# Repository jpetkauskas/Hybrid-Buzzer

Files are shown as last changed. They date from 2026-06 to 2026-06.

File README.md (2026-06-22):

# Hybrid Quiz Bowl Buzzers
***[Try a demo of the Reader Console here!](https://jpetkauskas.github.io/Hybrid-Buzzer/)***

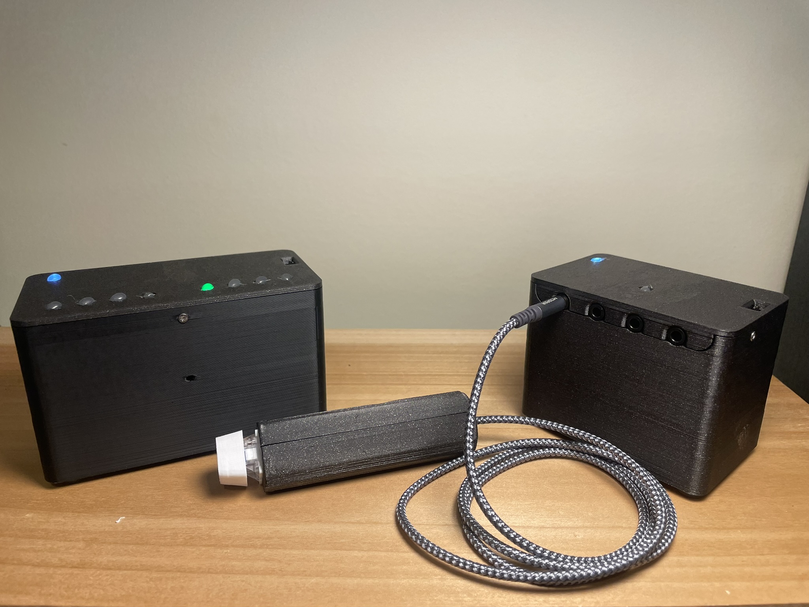
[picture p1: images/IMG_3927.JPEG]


This project uses three ESP32 based boards communicating via a unidirectional ESP-NOW link for robust, low latency Quizbowl lockout arbitration. A custom autopairing algorithm eliminates hardcoded MAC addresses and improves usability. The receiver also runs a novel SoftAP web server which hosts a scoring terminal for the reader, digitizing and simplifying tedious quizbowl scoring and adding analysis capability. Synchronized buzzer timing system  coordinates transmitter nodes based on receiver time, arbitrating winner based on incoming timestamps so that near-simultaneous buzzes aren't dropped, reaching 50/50 performance on true-simultaneous buzzes, 95/5 on 25uS deltas, and 100/0 correct arbitration for deltas >=50 uS (0.5 ms).

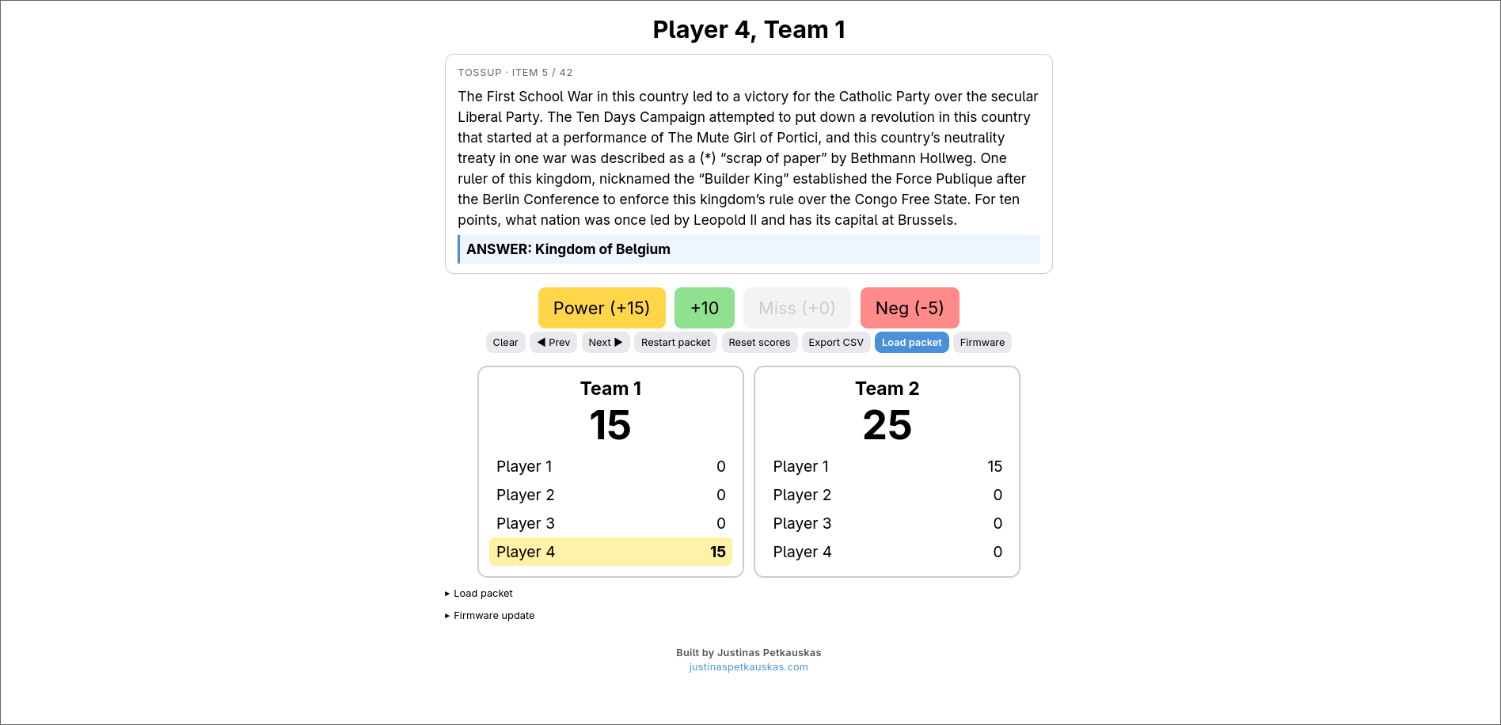
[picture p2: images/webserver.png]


I built these buzzers to replace my high school teams' aging wired set. The hybrid approach—wireless team stations with wired individual clickers—is more convenient than fully wired systems and scales more efficiently than fully wireless approaches. 

[See my writeup for more details.](https://justinaspetkauskas.com/writeups/hybrid-buzzers)

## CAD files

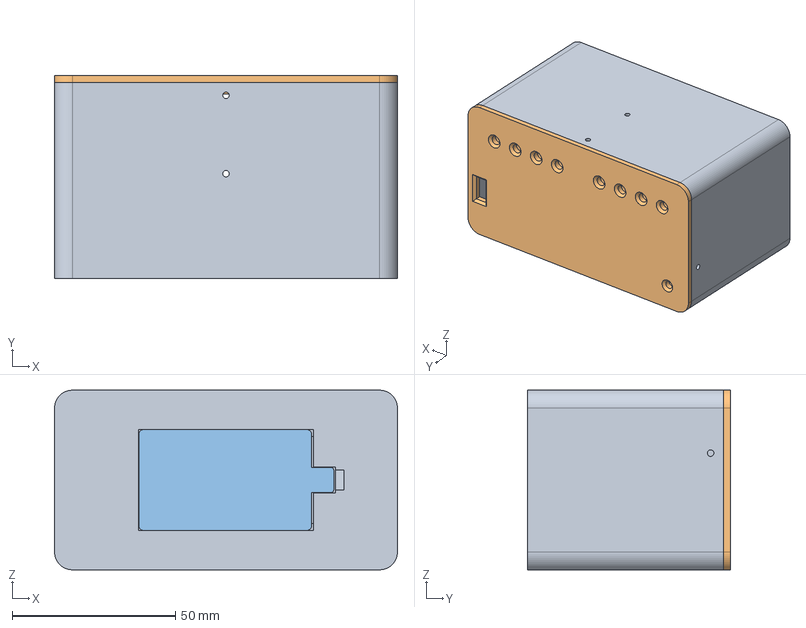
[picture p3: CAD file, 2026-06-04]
CAD/Receiver/receiver_assembly.stp
105.0 x 62.0 x 55.0 mm
receiver_enclosure
receiver_top_plate
receiver_battery_door

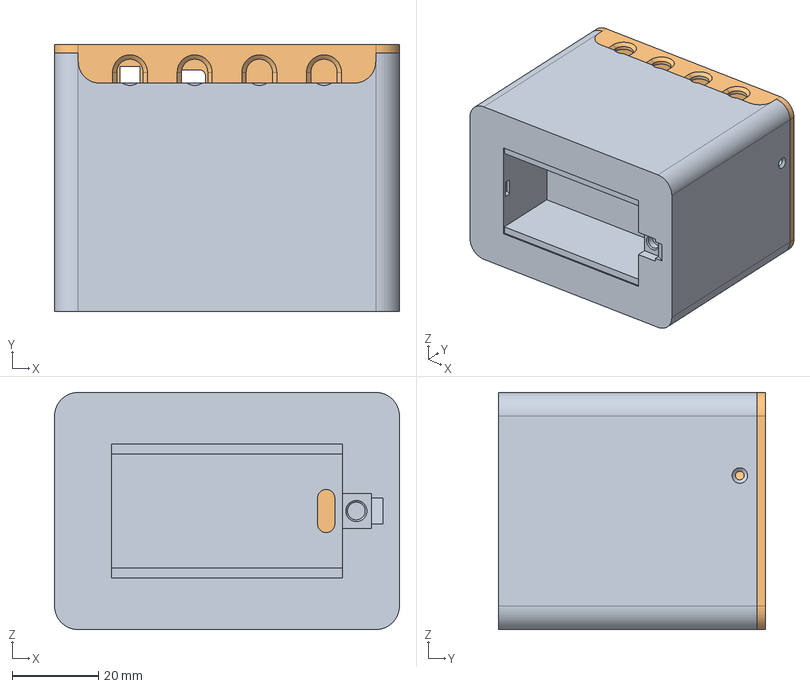
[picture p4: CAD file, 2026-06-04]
CAD/Transmitter/transmitter_assembly.stp
80.0 x 62.0 x 55.0 mm
transmitter_enclosure
transmitter_top_cover

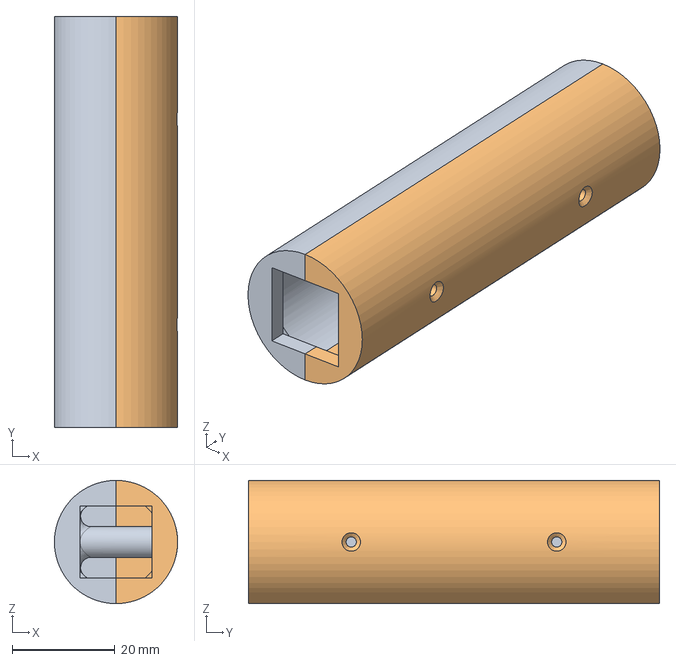
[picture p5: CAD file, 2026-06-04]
CAD/Clicker/Clicker.stp
24.0 x 80.0 x 24.0 mm
clicker_b
clicker_a

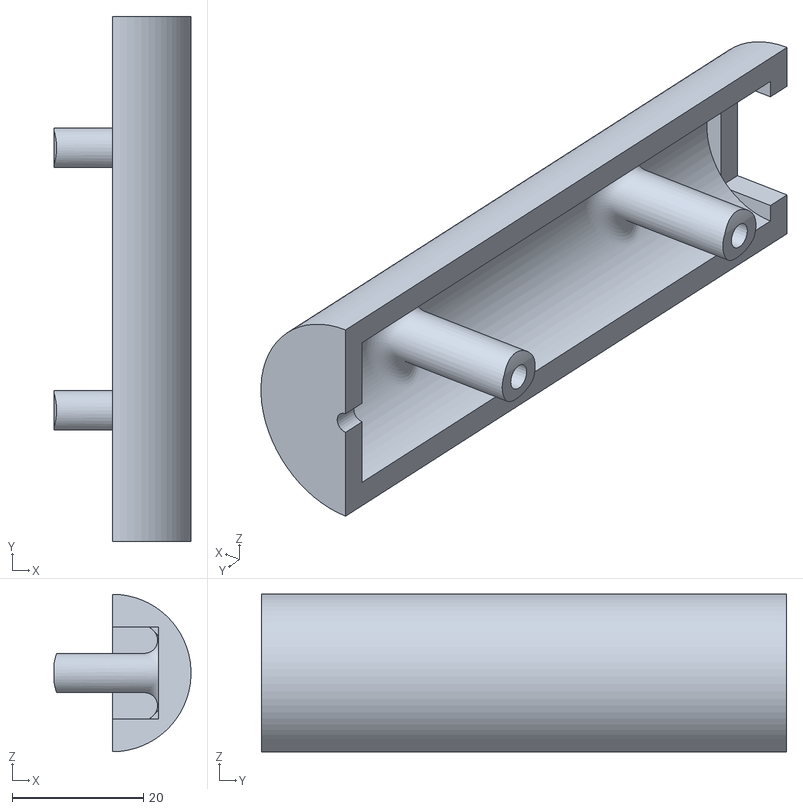
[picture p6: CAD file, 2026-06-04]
CAD/Clicker/Meshes/clicker_b.stl
20.9 x 80.0 x 24.0

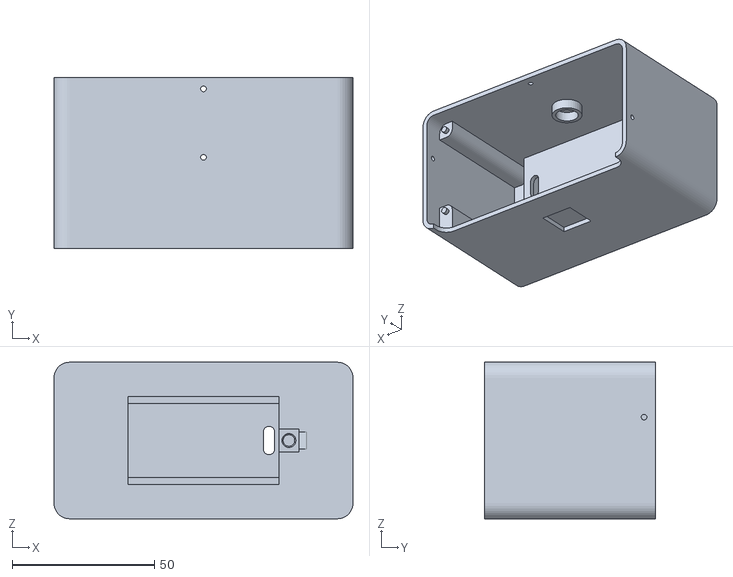
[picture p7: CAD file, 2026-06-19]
CAD/Receiver/Meshes/receiver_enclosure.stl
105.0 x 60.0 x 55.0

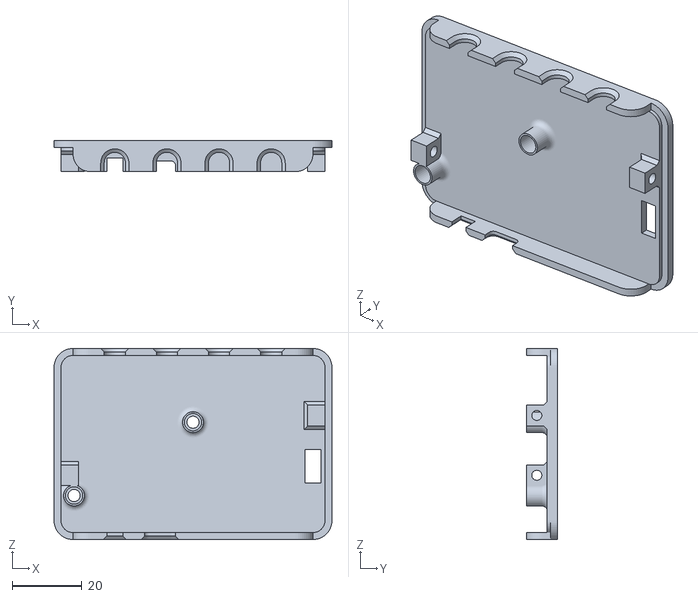
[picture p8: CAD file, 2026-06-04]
CAD/Transmitter/Meshes/transmitter_top_cover.stl
80.0 x 9.00 x 55.0

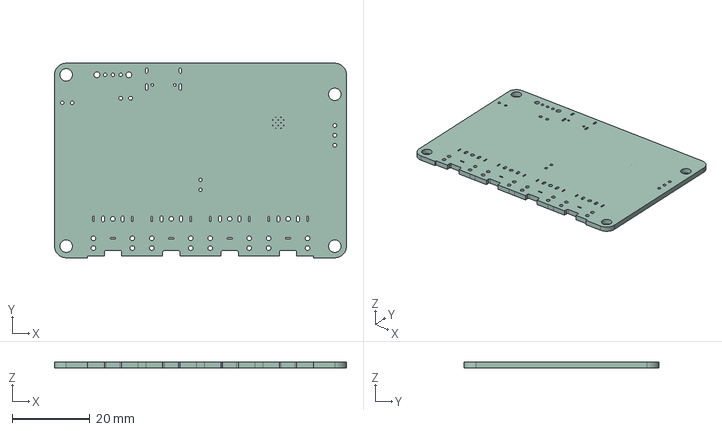
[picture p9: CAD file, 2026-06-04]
EDA/Transmitter/transmitter.step
75.0 x 50.0 x 1.51 mm

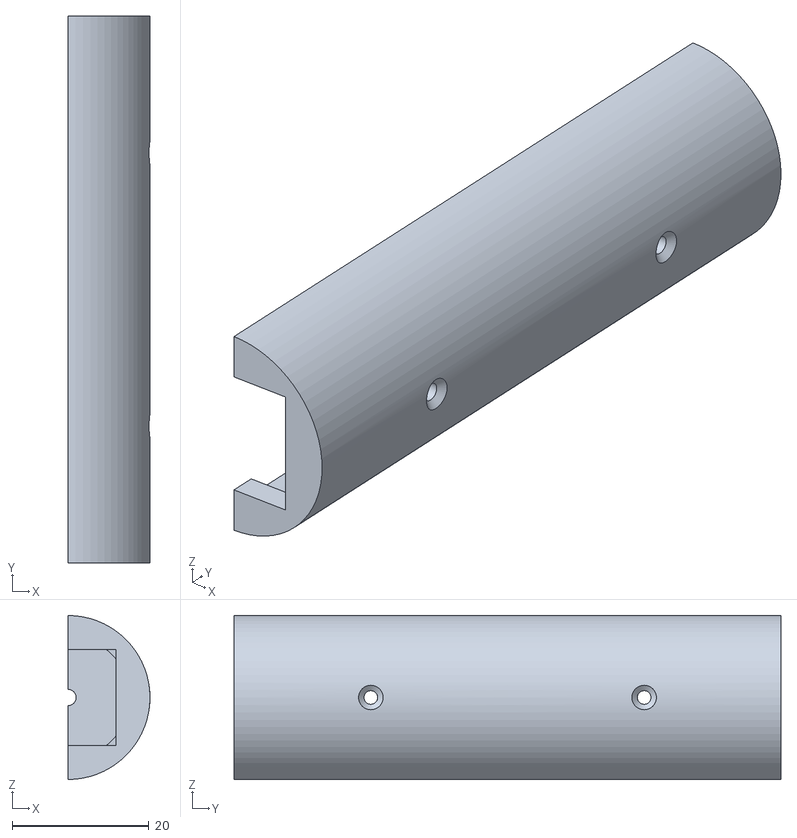
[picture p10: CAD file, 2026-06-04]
CAD/Clicker/Meshes/clicker_a.stl
12.0 x 80.0 x 24.0

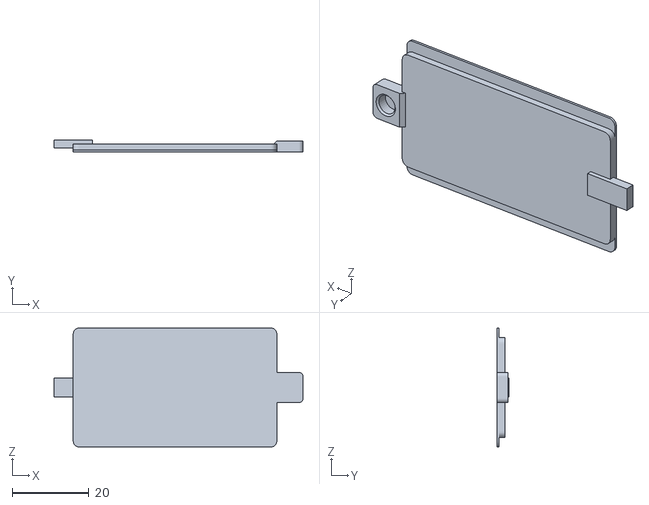
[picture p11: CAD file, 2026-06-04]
CAD/Receiver/Meshes/receiver_battery_door.stl
64.7 x 3.00 x 30.9

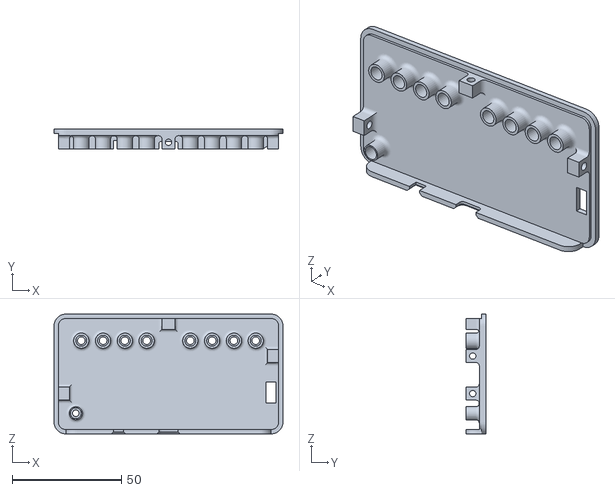
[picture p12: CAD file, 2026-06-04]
CAD/Receiver/Meshes/receiver_top_plate.stl
105.0 x 9.00 x 55.0

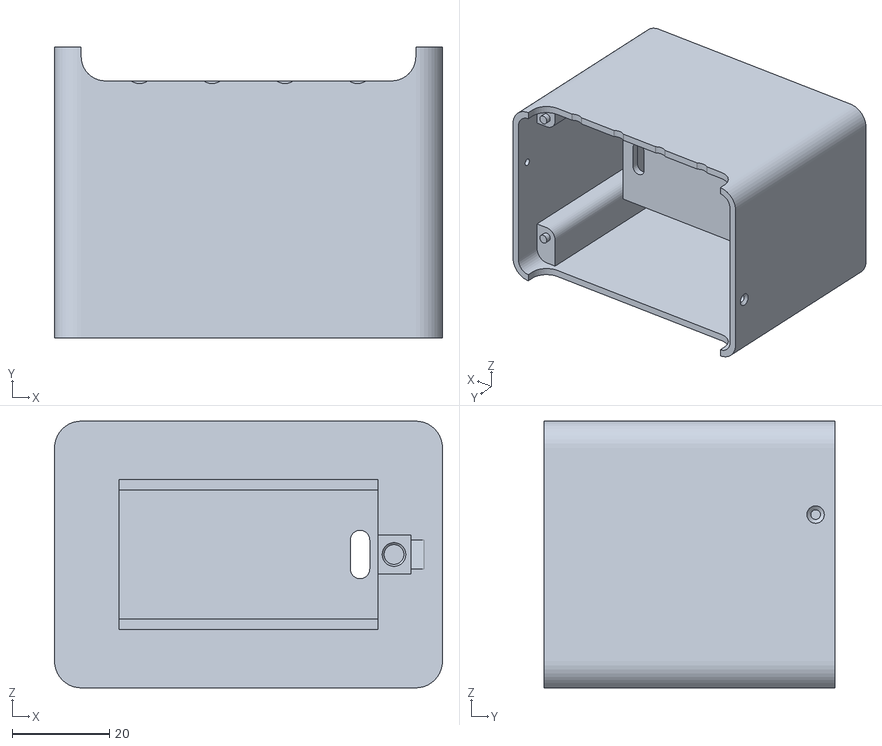
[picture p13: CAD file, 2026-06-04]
CAD/Transmitter/Meshes/transmitter_enclosure.stl
80.0 x 60.0 x 55.0

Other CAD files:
CAD/Clicker/Clicker.f3z
CAD/Receiver/receiver_assembly.f3z
CAD/Transmitter/transmitter_assembly.f3z

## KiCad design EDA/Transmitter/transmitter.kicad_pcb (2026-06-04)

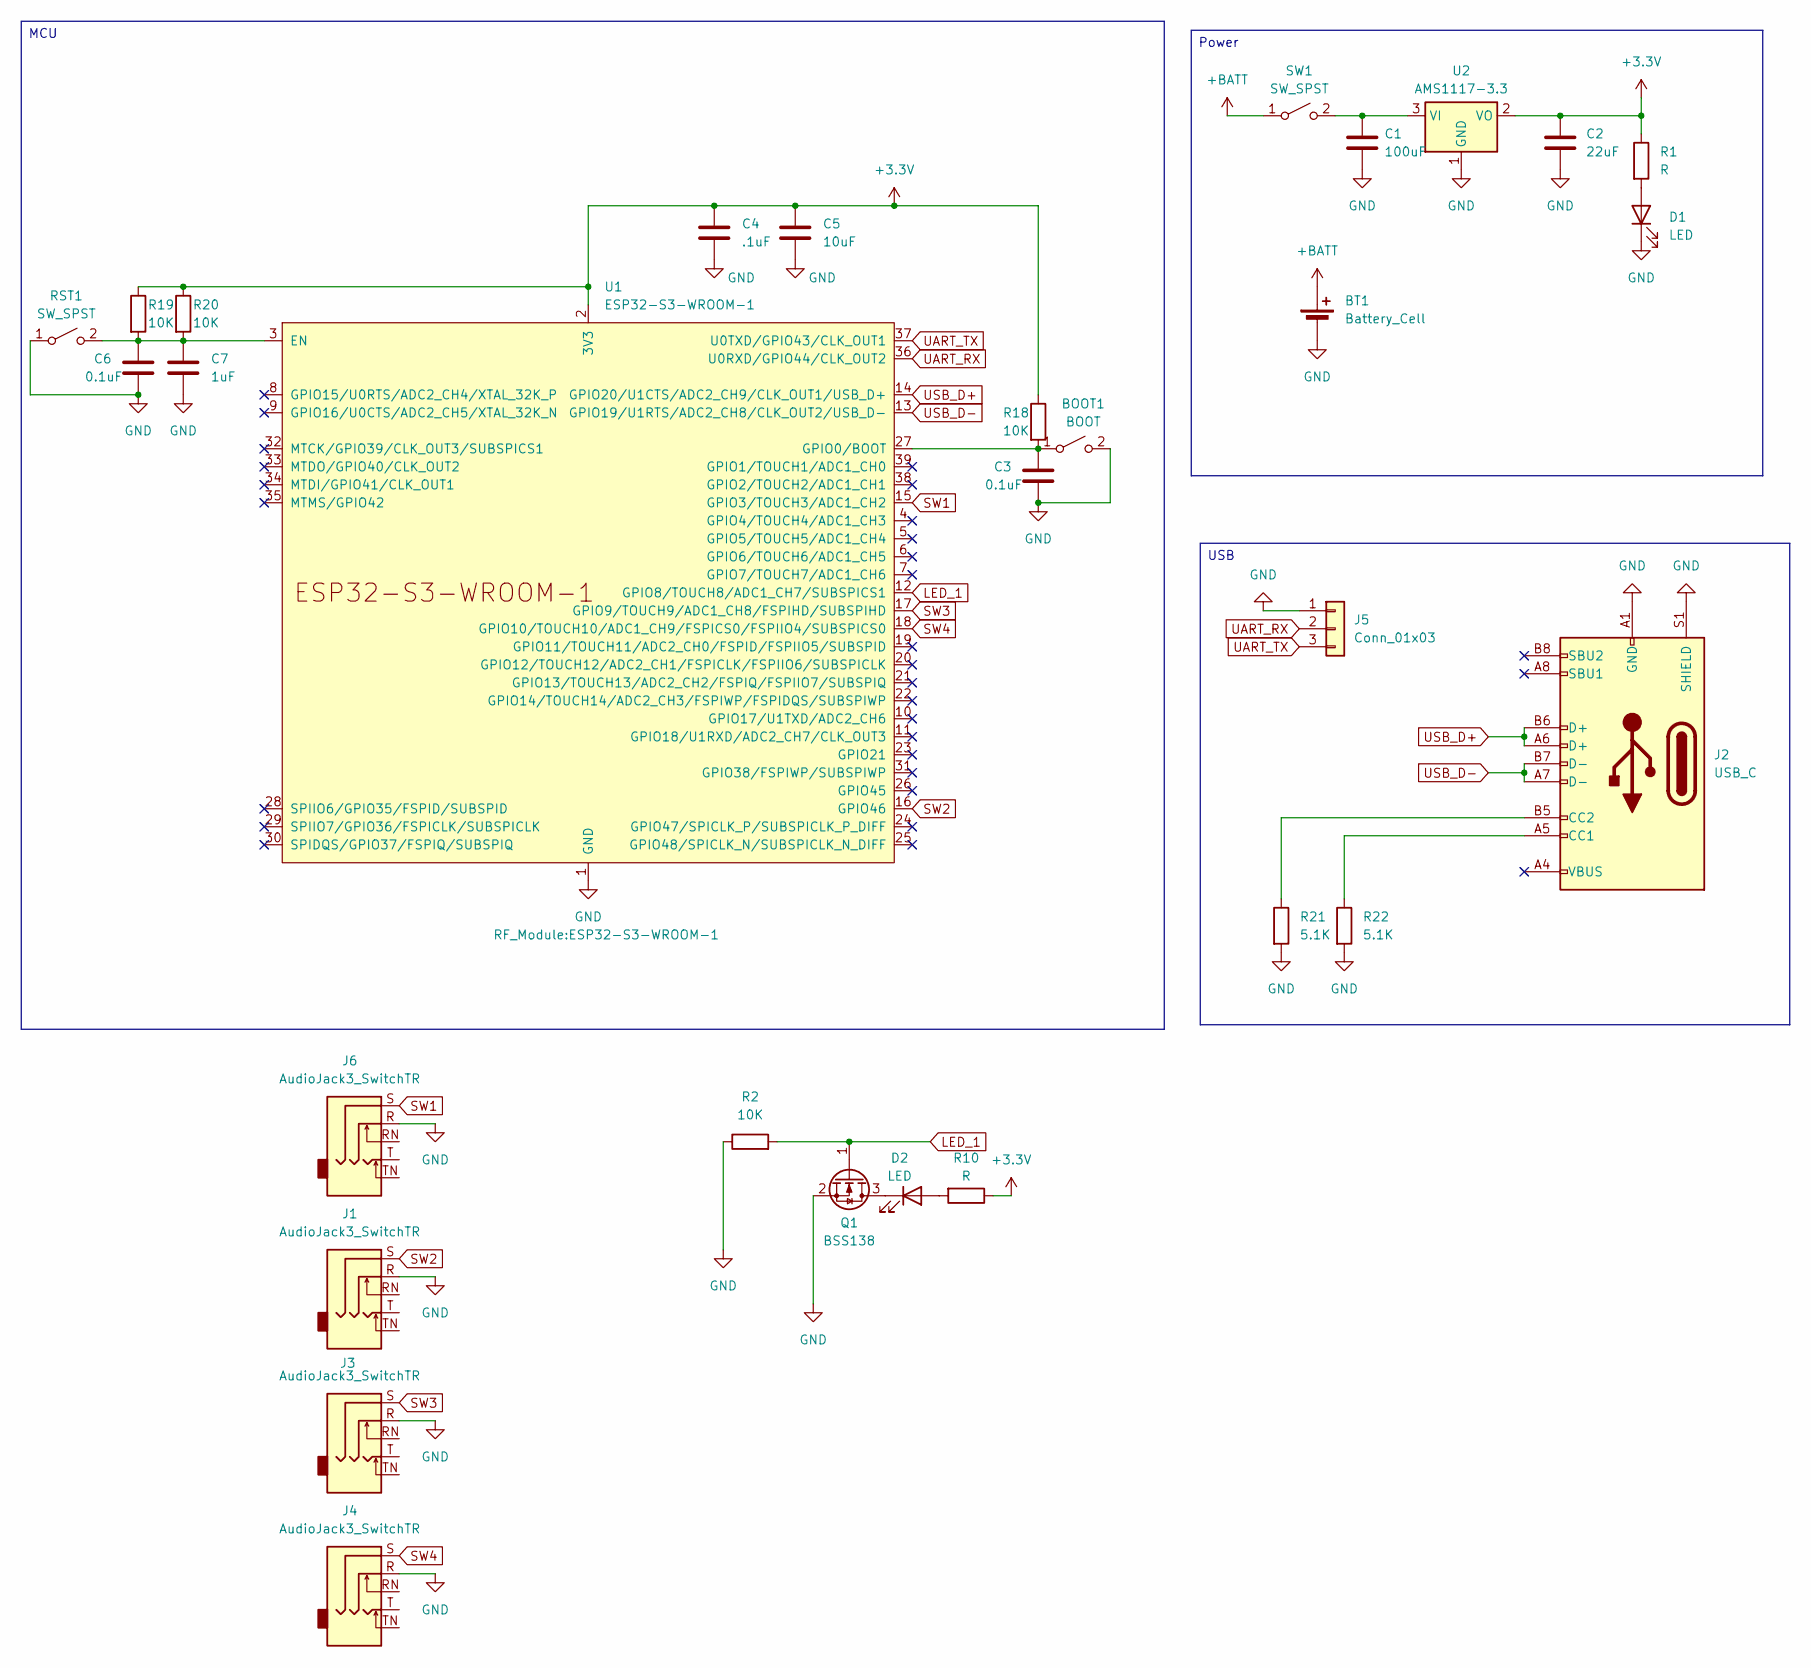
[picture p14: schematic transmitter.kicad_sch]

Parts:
BOOT1: BOOT; SW_SPST_B3U-1000P
BT1: Battery_Cell; PinHeader_1x02_P2.54mm_Vertical
C1: 100uF; C_0603_1608Metric
C2: 22uF; C_0603_1608Metric
C3, C6: 0.1uF; C_0603_1608Metric
C4: .1uF; C_0603_1608Metric
C5: 10uF; C_0603_1608Metric
C7: 1uF; C_0603_1608Metric
D1, D2: LED; LED_D3.0mm
J1, J3, J4, J6: AudioJack3_SwitchTR; Jack_3.5mm_CUI_SJ1-3525N_Horizontal
J2: USB_C; USB_C_Receptacle_G-Switch_GT-USB-7010ASV
J5: Conn_01x03; PinHeader_1x03_P2.54mm_Vertical
Q1: BSS138; SOT-23
R1, R10: R; R_0603_1608Metric
R2, R18, R19, R20: 10K; R_0603_1608Metric
R21, R22: 5.1K; R_0603_1608Metric
RST1: SW_SPST; SW_SPST_B3U-1000P
SW1: SW_SPST; SW_Slide_SPDT_Angled_CK_OS102011MA1Q
U1: ESP32-S3-WROOM-1
U2: AMS1117-3.3; SOT-223-3_TabPin2

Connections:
+3.3V: C2.1, C4.1, C5.1, R1.1, R10.1, R18.1, R19.1, R20.1, U1.2 (3V3), U2.2 (VO)
+BATT: BT1.1 (+), SW1.1 (A)
GND: BOOT1.2 (B), BT1.2 (-), C1.2, C2.2, C3.2, C4.2, C5.2, C6.2, C7.2, D1.1 (K), J1.R, J2.A1 (GND), J2.A12 (GND), J2.B1 (GND), J2.B12 (GND), J2.S1 (SHIELD), J3.R, J4.R, J5.1, J6.R, Q1.2 (S), R2.1, R21.2, R22.2, RST1.1 (A), U1.1 (GND), U1.40 (GND), U1.41 (GND), U2.1 (GND)
LED_1: Q1.1 (G), R2.2, U1.12 (GPIO8/TOUCH8/ADC1_CH7/SUBSPICS1)
unnamed: BOOT1.1 (A), C3.1, R18.2, U1.27 (GPIO0/BOOT)
unnamed: D1.2 (A), R1.2
unnamed: D2.2 (A), R10.2
unnamed: D2.1 (K), Q1.3 (D)
unnamed: J2.A5 (CC1), R22.1
unnamed: J2.B5 (CC2), R21.1
unnamed: C6.1, C7.1, R19.2, R20.2, RST1.2 (B), U1.3 (EN)
unnamed: C1.1, SW1.2 (B), U2.3 (VI)
SW1: J6.S, U1.15 (GPIO3/TOUCH3/ADC1_CH2)
SW2: J1.S, U1.16 (GPIO46)
SW3: J3.S, U1.17 (GPIO9/TOUCH9/ADC1_CH8/FSPIHD/SUBSPIHD)
SW4: J4.S, U1.18 (GPIO10/TOUCH10/ADC1_CH9/FSPICS0/FSPIIO4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)
UART_RX: J5.2, U1.36 (U0RXD/GPIO44/CLK_OUT2)
UART_TX: J5.3, U1.37 (U0TXD/GPIO43/CLK_OUT1)
USB_D+: J2.A6 (D+), J2.B6 (D+), U1.14 (GPIO20/U1CTS/ADC2_CH9/CLK_OUT1/USB_D+)
USB_D-: J2.A7 (D-), J2.B7 (D-), U1.13 (GPIO19/U1RTS/ADC2_CH8/CLK_OUT2/USB_D-)

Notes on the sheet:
USB
MCU
Power

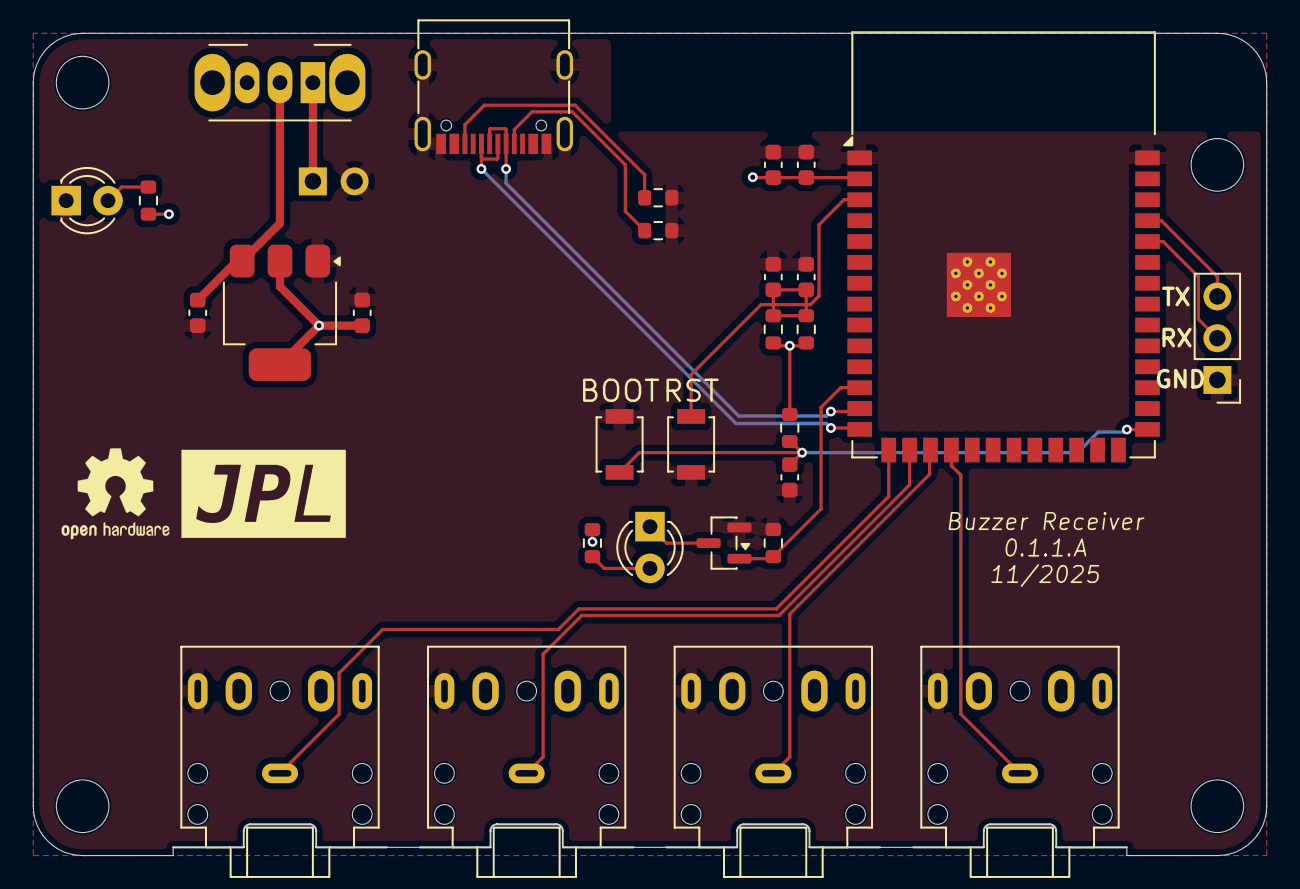
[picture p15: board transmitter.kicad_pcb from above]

Board: 2 copper layers, 75.0 x 50.0 mm, 30 parts (1 on the bottom side), 20 nets.

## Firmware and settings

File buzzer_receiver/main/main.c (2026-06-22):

#include "driver/gpio.h"
#include "esp_chip_info.h"
#include "esp_flash.h"
#include "esp_now.h"
#include "esp_system.h"
#include "esp_timer.h"
#include "esp_wifi.h"
#include "freertos/FreeRTOS.h"
#include "freertos/projdefs.h"
#include "freertos/queue.h"
#include "freertos/task.h"
#include "nvs_flash.h"
#include "packet.h"
#include "portmacro.h"
#include "sdkconfig.h"
#include <inttypes.h>
#include <stdint.h>
#include <stdio.h>
#include <string.h>

#include "button.h"
#include "buzz.h"
#include "config.h"
#include "webserver.h"
#include "wireless.h"

void app_main(void)
{
  q = xQueueCreate(10, sizeof(packet)); //FreeRTOS packet

  receiver_init_gpio(); //GPIO helper

  init_buzz(); //initializes buzzer FreeRTOS overhead

  send_buzz(&bn[0]); //buzz once on powerup

  init_sync_task(); //must come before receiver_init_wireless

  receiver_init_wireless(); //espnow overhead + autopair, returns once ready

  while (1)
  {
    packet first;
    if (xQueueReceive(q, &first, portMAX_DELAY) != pdTRUE) continue;

    if (latch_state) continue; /* discard packets that arrived while latched */

    /* Collect a competing packet within the arbitration window. */
    packet winner = first;
    packet competitor;
    bool contested = false;
    if (xQueueReceive(q, &competitor, pdMS_TO_TICKS(20)) == pdTRUE)
    {
      contested = true;
      if (competitor.timestamp_us < winner.timestamp_us)
      {
        winner = competitor;
      }
    }

    latch_state = true;

    int8_t team   = winner.transmitter_id;
    int8_t player = winner.player_id;

    gpio_set_level(led_array[(team * 4) + player - 1], 1);

    buzz_profile *bp = &bn[team];
    xQueueSend(buzz_queue, &bp, 0);

    webserver_set_winner(team, player);
  }
}

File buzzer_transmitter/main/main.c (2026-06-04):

#include "driver/gpio.h"
#include "esp_now.h"
#include "esp_timer.h"
#include "esp_wifi.h"
#include "freertos/queue.h"
#include "freertos/task.h"
#include "led.h"
#include "packet.h"
#include <stdint.h>
#include <stdio.h> 

#include "config.h"
#include "wireless.h"

void app_main(void) {
  q = xQueueCreate(10, sizeof(packet));  // FreeRTOS queue

  init_transmitter_gpio(q);  // initializes GPIO

  led_init(); //initializes LED freeRTOS task

  init_transmitter_wireless();   //initializes ESPNOW and returns when paired to receiver

  while (1) {
    if (xQueueReceive(q, &data, portMAX_DELAY)) 
    {
      esp_now_send(receiver_mac, (uint8_t *)&data, sizeof(data));
      printf("Pin %d fired\n", data.player_id);
      led_trigger();
    }
  }
}

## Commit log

2026-05-06 fixed pin 3 bug
    [main.c]
2026-05-06 breaks in switch
2026-05-16 refactored receiver buzz scheduling
    [main.c]
2026-05-29 memcpy mac comparison (doesn't work)
    [main.c, wireless.c]
2026-05-29 led initialization before flashing
2026-05-29 transmitter-side wireless pairing protocol
2026-05-30 autopair+semaphor unblocking, unresolved bug causes crash after buzz
    [wireless.c]
2026-05-31 autopair algorithm complete, memcmp bug unresolved
    [main.c, wireless.c]
2026-06-04 Print arbitration winner to webserver
2026-06-04 clear button
2026-06-07 ota updates, quality of life
    [partitions.csv]
2026-06-07 comment out print statements
